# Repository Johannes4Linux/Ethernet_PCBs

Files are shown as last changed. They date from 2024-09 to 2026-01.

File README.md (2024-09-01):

# PCBs for GNU/Linux & Ethernet Tutorials

This repositroy contains the KiCad Designs for the following PCBs:

- W7500 MAC Card: A PCB with the Wiznet W7500 chip which can be used as an SPI to Ethernet card. The PCB allows access to the MII over a pinheader and various Ethernet Transceiver Evaluation Boards can be connected to it.
- LAN8710A Ethernet Transceiver Card: PCB with the Microchip LAN8710A Ethernet Transceiver. The PCB can be connected to the *W7500 MAC Card* over the MII pinheader

## License

This documentation describes Open Hardware and is licensed under the CERN OHL S v2.

You may redistribute and modify this documentation under the terms of the CERN OHL S v2 ([http://ohwr.org/cernohl](http://ohwr.org/cernohl)). This documentation is distributed WITHOUT ANY EXPRESS OR IMPLIED WARRANTY, INCLUDING OF MERCHANTABILITY, SATISFACTORY QUALITY AND FITNESS FOR A PARTICULAR PURPOSE. Please see the CERN OHL S v2 for applicable conditions.

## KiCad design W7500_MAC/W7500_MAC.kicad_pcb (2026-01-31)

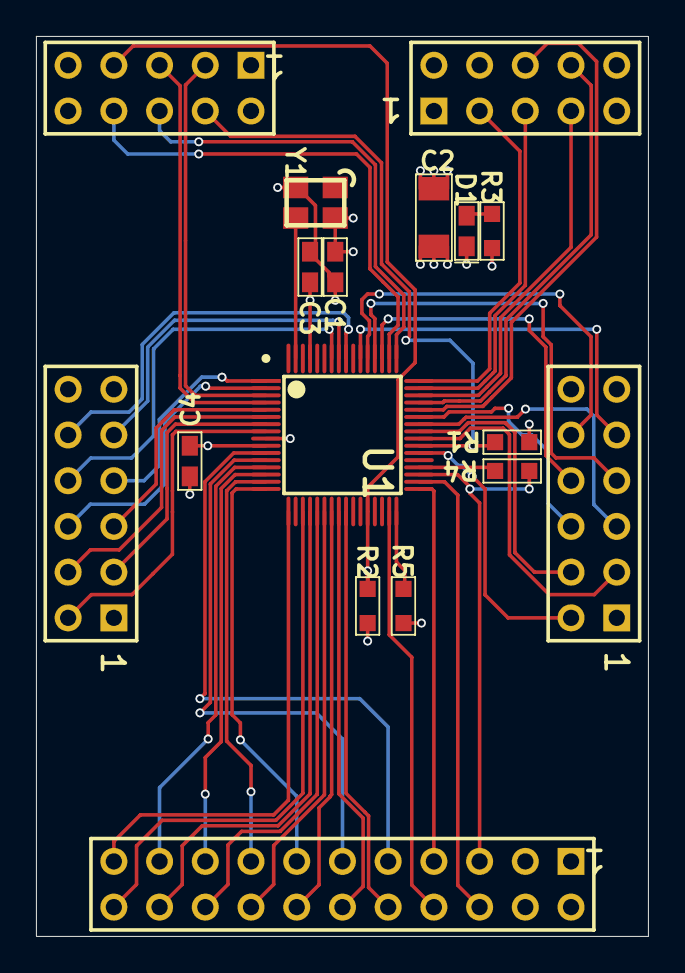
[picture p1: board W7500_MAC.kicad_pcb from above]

Board: 4 copper layers, 34.0 x 50.0 mm, 17 parts (0 on the bottom side), 53 nets.

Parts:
C1, C3, C4: 100nF 0603; 0603_CAP
C2: 10uF 1206; 1206_CAP
D1: LED0; 0603_LED
P1, P4: Header 5X2; HDR2X5
P2, P3: Header 6X2; HDR2X6
P5: Header 11X2H; HDR2X11
R1, R2, R5: 4k7 0603; 0603
R3, R4: 330R 0603; 0603
U1: W7500; W7500_64pin
Y1: 8MHz 3225; XTAL_3225

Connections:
BOOT: P1.4, R1.2, U1.39
COL: P5.10, U1.25
CRS: P5.9, U1.11
CS: P4.8, U1.45
GND: C1.1, C2.1, C3.1, C4.1, D1.2, P1.9, P1.10, P2.11, P2.12, P3.11, P3.12, P4.4, P4.9, P5.3, P5.4, R1.1, R5.1, U1.9, Y1.2
IRQ: P4.6, U1.44
ISP_RXD: P1.5, U1.4
ISP_TXD: P1.3, U1.3
MDC: P5.6, U1.34
MDIO: P5.5, R4.1, U1.35
MISO: P4.5, U1.47
MOSI: P4.3, U1.48
NetD1_1: D1.1, R3.1
NetR4_2: R4.2, U1.36
NetU1_63: U1.63, Y1.3
PA_10: P2.2, U1.38
PA_11: P2.3, U1.40
PA_12: P2.4, U1.41
PA_13: P2.5, U1.42
PA_14: P2.6, U1.43
PC_00: P2.10, U1.53
PC_01: P2.9, U1.54
PC_03: P3.10, U1.56
PC_04: P3.9, U1.57
PC_05: P3.8, U1.58
PC_06: P2.8, U1.51
PC_07: P2.7, U1.52
PC_08: P3.7, U1.1
PC_09: P3.6, U1.2
PC_12: P3.5, U1.5
PC_13: P3.4, U1.6
PC_14: P3.3, U1.7
PC_15: P3.2, U1.8
PHY_IRQ: P5.8, U1.31
PHY_RST: P5.7, U1.33
RESET: P1.7, R2.1, U1.28
RXCLK: P5.21, U1.17
RXD0: P5.19, U1.13
RXD1: P5.17, U1.14
RXD2: P5.15, U1.15
RXD3: P5.13, U1.16
RXDV: P5.11, U1.12
SCLK: P4.7, U1.46
SWD_SWDCLK: P1.6, U1.49
SWD_SWDIO: P1.8, U1.50
TEST: R5.2, U1.32
TXCLK: P5.22, U1.19
TXD0: P5.20, U1.20
TXD1: P5.18, U1.21
TXD2: P5.16, U1.22
TXD3: P5.14, U1.23
TXEN: P5.12, U1.24
VCC_3V3: C1.2, C2.2, C3.2, C4.2, P1.1, P1.2, P2.1, P3.1, P4.1, P5.1, P5.2, R2.2, R3.2, U1.10, U1.61, Y1.4

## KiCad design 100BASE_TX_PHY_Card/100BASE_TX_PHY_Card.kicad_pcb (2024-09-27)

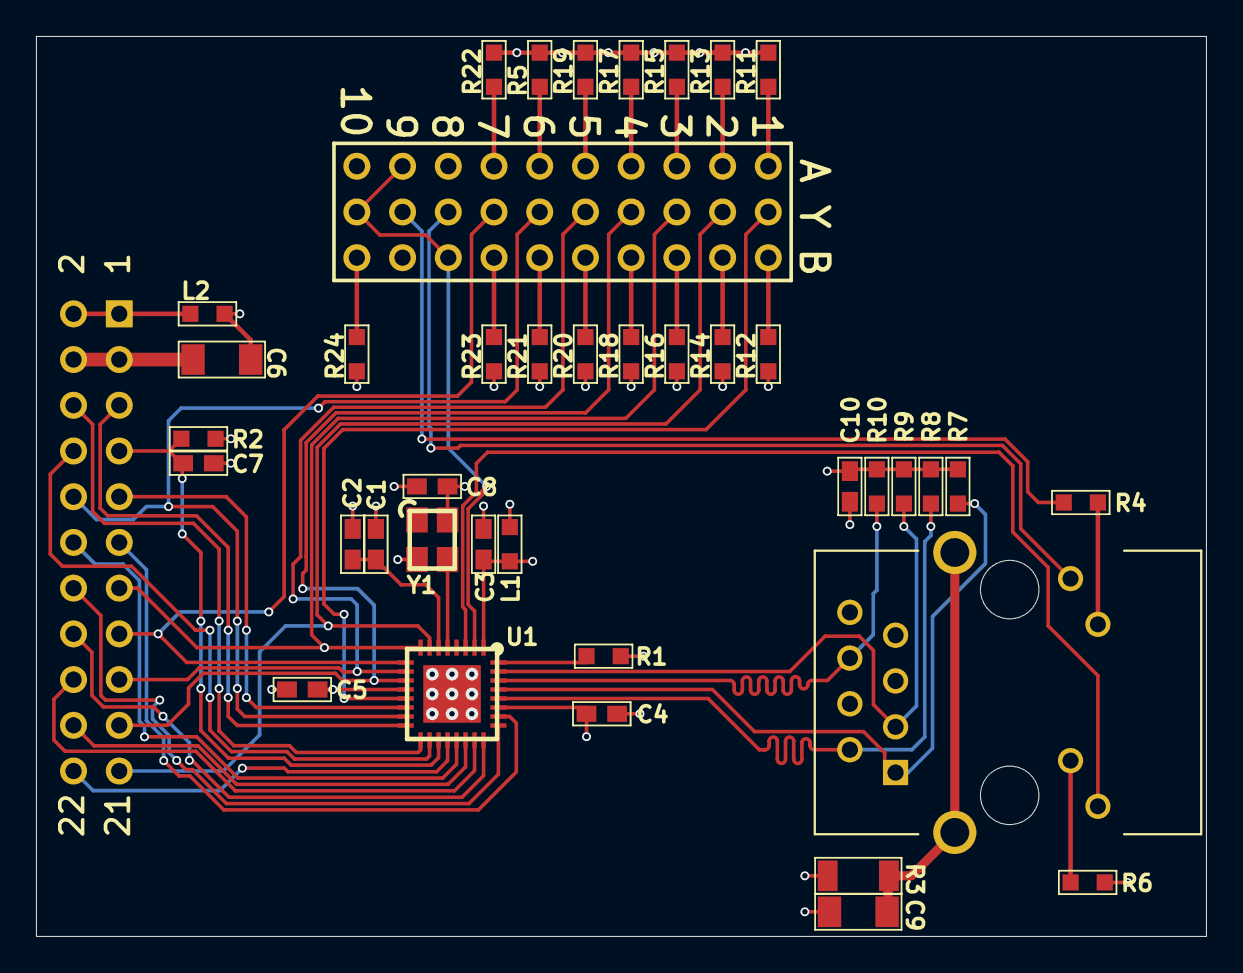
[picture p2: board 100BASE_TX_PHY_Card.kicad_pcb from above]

Board: 4 copper layers, 65.0 x 50.0 mm, 41 parts (1 on the bottom side), 52 nets.

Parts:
C1: 470pF 0603; 0603_CAP
C2: 1uF 0603; 0603_CAP
C3, C4, C5, C7, C8: 100nF 0603; 0603_CAP
C6: 10uF 1206; 1206_CAP
C9: 10nF; 1206_CAP
C10: 15pF 0603; 0603_CAP
L1, L2: Ferrite bead 120R/100MHz; 0603_IND
P1: RJMG1BD3B8K1ANR
P2: SELECTOR 10WAY; SELECTOR_10WAY
P3: Header 11X2H; HDR2X11H
R1: 12k1 0603; 0603
R2: 100k 0603; 0603
R3: 1M 1206; 1206
R4, R6: 330R 0603; 0603
R5, R11, R12, R13, R14, R15, R16, R17, R18, R19, R20, R21, R22, R23, R24: 10k 0603; 0603
R7, R8, R9, R10: 49R9 0603; 0603
U1: LAN8710A
Y1: 25MHz 3225; XTAL_3225

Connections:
/MODE0: P2.11, P3.19, U1.11
/MODE1: P2.14, P3.17, U1.10
/MODE2: P2.17, P3.10, U1.15
/PHYAD0: P2.2, U1.13
/PHYAD1: P2.5, P3.21, U1.7
/PHYAD2: P2.8, P3.13, U1.8
/RMIISEL: P2.20, P3.15, U1.9
CRS: P3.9, U1.14
GND: C1.1, C2.1, C3.1, C4.1, C5.1, C6.1, C7.1, C8.1, C9.1, C10.1, P1.8, P2.27, P3.3, P3.4, R1.2, R3.2, R6.2, R12.1, R14.1, R16.1, R18.1, R20.1, R21.1, R23.1, R24.1, U1.0, Y1.2
LED1: P1.L4, U1.3
LED2: P2.24, P2.25, P2.29, U1.2
LED2+: P1.L1, P2.23
LED2-: P2.26, R4.2
MDC: P3.6, U1.17
MDIO: P3.5, U1.16
NetP1_L2: P1.L2, R4.1
NetP1_L3: P1.L3, R6.1
NetP2_1: P2.1, R11.2
NetP2_3: P2.3, R12.2
NetP2_4: P2.4, R13.2
NetP2_6: P2.6, R14.2
NetP2_7: P2.7, R15.2
NetP2_9: P2.9, R16.2
NetP2_10: P2.10, R17.2
NetP2_12: P2.12, R18.2
NetP2_13: P2.13, R19.2
NetP2_15: P2.15, R20.2
NetP2_16: P2.16, R5.2
NetP2_18: P2.18, R21.2
NetP2_19: P2.19, R22.2
NetP2_21: P2.21, R23.2
NetP2_30: P2.30, R24.2
NetR1_1: R1.1, U1.32
NetU1_5: U1.5, Y1.3
PHY_IRQ: P3.8, U1.18
PHY_RST: C7.2, P3.7, R2.1, U1.19
RXDV: P3.11, U1.26
RX_n: P1.6, R10.2, U1.30
RX_p: P1.3, R9.2, U1.31
SHIELD: C9.2, P1.S, R3.1
TXCLK: P3.22, U1.20
TXD0: P3.20, U1.22
TXD1: P3.18, U1.23
TXD2: P3.16, U1.24
TXD3: P3.14, U1.25
TXEN: P3.12, U1.21
TX_n: P1.2, R8.2, U1.28
TX_p: P1.1, R7.2, U1.29
VCC_3V3: L1.2, L2.2, P3.1, P3.2, R2.2, R5.1, R11.1, R13.1, R15.1, R17.1, R19.1, R22.1
VDDCR: C1.2, C2.2, U1.6
VDDIO: C5.2, C6.2, C8.2, L2.1, U1.12, Y1.4
VDD_A: C3.2, C4.2, C10.2, L1.1, P1.4, P1.5, P2.22, R7.1, R8.1, R9.1, R10.1, U1.1, U1.27

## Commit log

2024-09-01 Upload first draft of W7500 MAC card design and LAN8710A card schematic
    [100BASE_TX_PHY_Card.kicad_pcb, 100BASE_TX_PHY_Card.kicad_sch, SPI_IRQ.kicad_sch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]
2024-09-27 LAN8710A PHY Card 4layer design
    [100BASE_TX_PHY_Card.kicad_pcb, 100BASE_TX_PHY_Card.kicad_sch]
2024-09-28 Added missing Connectors schematic
    [100BASE_TX_PHY_Card.kicad_sch, Connectors.kicad_sch]

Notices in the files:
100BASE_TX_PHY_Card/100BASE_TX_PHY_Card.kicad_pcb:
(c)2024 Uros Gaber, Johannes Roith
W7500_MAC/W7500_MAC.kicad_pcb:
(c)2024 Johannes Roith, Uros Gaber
